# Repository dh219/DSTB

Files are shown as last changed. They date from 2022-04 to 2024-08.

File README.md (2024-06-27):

## David's ST Booster (DSTB)

# WARNING 27 July 2024 #

I strongly recommend no new builds of this project for now. I believe there's a reliabiltiy of executing from AltRAM which I've not been able to get to the bottom of.

Memory tests pass reliably, but I think the approach to this design in combination with clock switching and attempting to service DMA is inherently flawed.

Unless I find a firmware fix, in which case I'll log that here, I recommend persuing other designs or waiting for a revision 2.

David.

---

#### A low-cost DIY 16MHz 68000 accelerator with 8MB fast AltRAM and optional ROM cacheing

Fitting into a small footprint, just 3mm wider than the 68000 socket into which this plugs, the board (\~$4) contains one XC95144XL-100 CPLD (\~$5), one 32Mbit TSSOP-II-54 SDRAM chip (~$5), two level-shifting buffers (\~$6), one 5 or 3.3V 66MHz oscillator in a 7x5mm package (\~$4) and a 3.3V LDO voltage regulator (\~$2) as the core components.

This provides all the interface between the ST and a 16MHz capable 68000. The 68000 will run at the oscillator frequency divided by four, so 16.5MHz in normal configuration.

The AltRAM runs at at full speed for a 16MHz processor, offering throughput of around 7.7MB/s compared to ST-RAM's 3.7MB/s.

Firmware source (ISE), board design files (KiCAD) and any source for support programs will be published at each release.

#### Cost & requirements

I anticipate a single board can be hand assembled for approximately 30USD. You may need to acquire a 16MHz capable DIP-64 68000 to pair with it if your old 8MHz chip cannot handle the faster clock.

#### Manual

At the moment, there is no manual. This will be written in due course.

There is a build video available at https://youtu.be/VHx3kat0Q6M

### Resistor Networks

All resistor networks are recommended, however if you have already carried out preventative maintenance on your ST board such that the bus resistor packs have been changed to 2k2 or lower, you may omit the resistor packs on the address and data bus (RN1-10).

Please note, RN11 is not a supplementary bus pull-up pack and is required for correct operation of the firmware.

#### Software

See https://github.com/dh219/DSTB-tools for the 'AltRAM' or 'AltROM' programs (NB. 'AltROM' hasn't been properly tested with later firmware builds & this board is not compatible with 'ExxosRAM.PRG').

EmuTOS automatically recognises and activate AltRAM.

---

*Copyright 2022 D Henderson, released under GPL2.0*

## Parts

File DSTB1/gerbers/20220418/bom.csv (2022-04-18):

Comment | Designator | Footprint | LCSC Part #
100n Unpolarized capacitor | C1,C3,C5,C7,C9 | C_0805_2012Metric_Pad1.18x1.45mm_HandSolder
10u Unpolarized capacitor | C4,C8,C10 | C_0805_2012Metric_Pad1.18x1.45mm_HandSolder
LED Light emitting diode | D1 | LED_0805_2012Metric_Pad1.15x1.40mm_HandSolder
IS42S16320D-7TL | IC1 | TSOP-II-54_22.2x10.16mm_P0.8mm
SN74CB3T3245PW Texas Instruments SN74CB3T3245DW, Bus Switch, 8 x 1:1, 2.3 3.6 V, 20-Pin SOIC | IC2,IC3 | TSSOP-20_4.4x6.5mm_P0.65mm | C7145
Conn_01x06_Male Generic connector, single row, 01x06, script generated (kicad-library-utils/schlib/autogen/connector/) | J1 | PinHeader_1x06_P2.54mm_Horizontal
1k Resistor | R1 | R_0805_2012Metric_Pad1.20x1.40mm_HandSolder
2k2 Resistor | R2 | C_0805_2012Metric_Pad1.18x1.45mm_HandSolder
3k3 4 resistor network, parallel topology | RN1,RN2,RN3,RN4,RN5,RN6,RN7,RN8,RN9,RN10,RN11 | R_Array_Convex_4x0603
68000D 16/32-bit Microprocessor | U1 | DIP-64_W22.86mm
68000D 16/32-bit Microprocessor | U2 | DIP-64_W22.86mm_Socket
XC95144XL-TQ100 CPLD, 144 Macrocells, 3200 Usable Gates | U3 | TQFP-100_14x14mm_P0.5mm
LT1129-3.3_SOT223 700mA Micropower Low drop-out regulator, Fixed Output 3.3V, SOT-223 | U4 | SOT-223-3_TabPin2
IQXO-70 Crystal Clock Oscillator, SMD package 7.5x5.0mm² | X1 | Oscillator_SMD_IQD_IQXO70-4Pin_7.5x5.0mm

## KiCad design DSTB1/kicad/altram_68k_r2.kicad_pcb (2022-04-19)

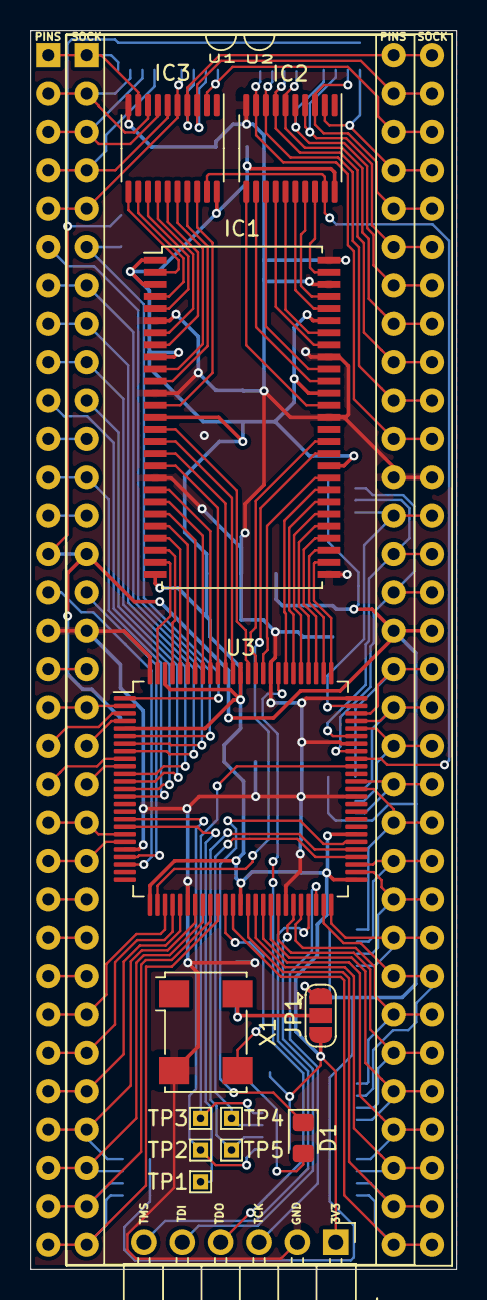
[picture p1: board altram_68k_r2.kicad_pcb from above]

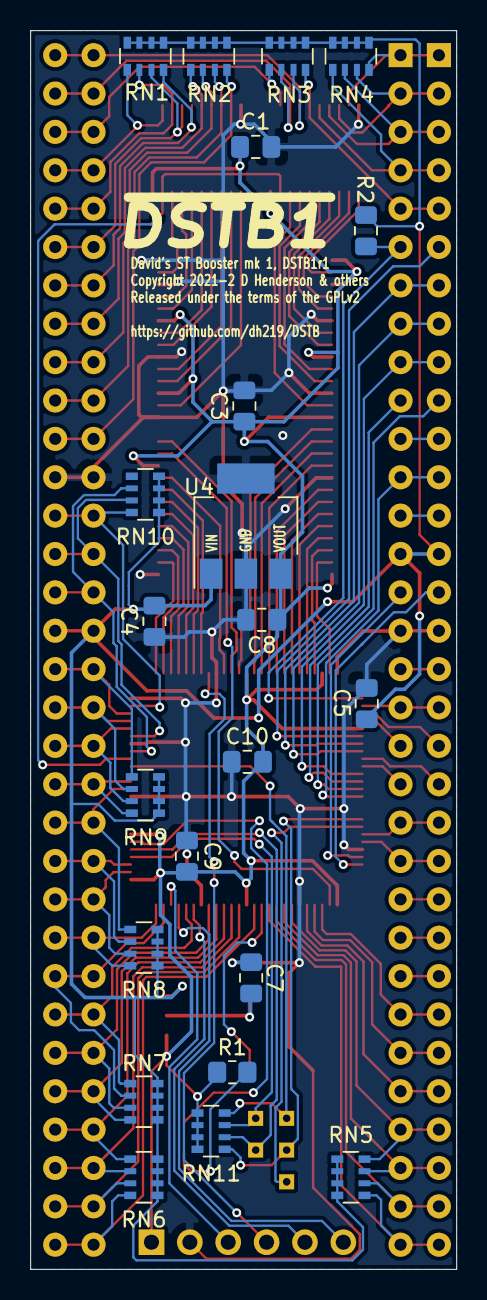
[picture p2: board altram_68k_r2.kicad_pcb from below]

Board: 2 copper layers, 28.2 x 82.0 mm, 37 parts (22 on the bottom side), 119 nets.

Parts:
C1, C3, C5, C7, C9: 100n; C_0805_2012Metric_Pad1.18x1.45mm_HandSolder
C4, C8, C10: 10u; C_0805_2012Metric_Pad1.18x1.45mm_HandSolder
D1: LED; LED_0805_2012Metric_Pad1.15x1.40mm_HandSolder
IC1: IS42S16320D-7TL; TSOP-II-54_22.2x10.16mm_P0.8mm
IC2, IC3: SN74CB3T3245PW; TSSOP-20_4.4x6.5mm_P0.65mm
J1: Conn_01x06_Male; PinHeader_1x06_P2.54mm_Horizontal
JP1: SolderJumper_3_Open; SolderJumper-3_P1.3mm_Open_RoundedPad1.0x1.5mm
R1: R; R_0805_2012Metric_Pad1.20x1.40mm_HandSolder
R2: 2k2; C_0805_2012Metric_Pad1.18x1.45mm_HandSolder
RN1, RN2, RN3, RN4, RN5, RN6, RN7, RN8, RN9, RN10, RN11: 3k3; R_Array_Convex_4x0603
TP1, TP2, TP3, TP4, TP5: TestPoint; TestPoint_THTPad_1.0x1.0mm_Drill0.5mm
U1: 68000D; DIP-64_W22.86mm
U2: 68000D; DIP-64_W22.86mm_Socket
U3: XC95144XL-TQ100; TQFP-100_14x14mm_P0.5mm
U4: LT1129-3.3_SOT223; SOT-223-3_TabPin2
X1: IQXO-70; Oscillator_SMD_IQD_IQXO70-4Pin_7.5x5.0mm

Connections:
/LED1: D1.1, U3.56
/TCK: J1.3, U3.48
/TDI: J1.5, U3.45
/TDO: J1.4, U3.83
/TMS: J1.6, U3.47
/TP1: TP1.1, U3.18
/TP2: RN11.1, TP2.1, U3.17
/TP3: RN11.4, TP3.1, U3.66
/TP4: RN11.3, TP4.1, U3.54
/TP5: RN11.2, TP5.1, U3.55
A1: RN5.8, U1.29, U2.29, U3.32
A2: RN5.7, U1.30, U2.30, U3.33
A3: RN5.6, U1.31, U2.31, U3.34
A4: RN5.5, U1.32, U2.32, U3.35
A5: RN6.8, U1.33, U2.33, U3.37
A6: RN6.7, U1.34, U2.34, U3.39
A7: RN6.6, U1.35, U2.35, U3.40
A8: RN6.5, U1.36, U2.36, U3.41
A9: RN7.8, U1.37, U2.37, U3.42
A10: RN7.7, U1.38, U2.38, U3.43
A11: RN7.5, U1.39, U2.39, U3.46
A12: RN7.6, U1.40, U2.40, U3.49
A13: RN8.8, U1.41, U2.41, U3.50
A14: RN8.7, U1.42, U2.42, U3.52
A15: RN8.6, U1.43, U2.43, U3.53
A16: RN8.5, U1.44, U2.44, U3.63
A17: RN9.8, U1.45, U2.45, U3.64
A18: RN9.7, U1.46, U2.46, U3.71
A19: RN9.6, U1.47, U2.47, U3.72
A20: RN9.5, U1.48, U2.48, U3.73
A21: RN10.6, U1.50, U2.50, U3.68
A22: RN10.7, U1.51, U2.51, U3.70
A23: RN10.8, U1.52, U2.52, U3.74
BA0: IC1.20, U3.92
BA1: IC1.21, U3.93
BG: U1.11, U2.11
BGK: U1.12, U2.12, U3.14
BR: U1.13, U2.13
CLK8: U1.15, U3.23
CLKOUT: U2.15, U3.22
D0: IC3.5, RN3.4, U1.5, U2.5
D1: IC3.6, RN4.1, U1.4, U2.4
D2: IC3.7, RN4.2, U1.3, U2.3
D3: IC3.8, RN4.3, U1.2, U2.2
D4: IC3.9, RN4.4, U1.1, U2.1
D5: IC3.4, RN3.3, U1.64, U2.64
D6: IC3.3, RN3.2, U1.63, U2.63
D7: IC3.2, RN3.1, U1.62, U2.62
D8: IC2.2, RN1.1, U1.61, U2.61
D9: IC2.3, RN1.2, U1.60, U2.60
D10: IC2.4, RN1.3, U1.59, U2.59
D11: IC2.5, RN1.4, U1.58, U2.58
D12: IC2.6, RN2.1, U1.57, U2.57
D13: IC2.7, RN2.2, U1.56, U2.56
D14: IC2.8, RN2.3, U1.55, U2.55
D15: IC2.9, RN2.4, U1.54, U2.54
DQM0: IC1.15, U3.87
DQM1: IC1.39, U3.86
E: U1.20, U3.9
E_INT: U2.20, U3.10
FC0: U1.28, U2.28, U3.30
FC1: U1.27, U2.27, U3.29
FC2: U1.26, U2.26, U3.28
GND: C1.2, C3.2, C4.1, C5.1, C7.2, C8.2, C9.1, C10.1, IC1.6, IC1.12, IC1.19, IC1.28, IC1.41, IC1.46, IC1.52, IC1.54, IC2.10, IC3.10, J1.2, U1.16, U1.53, U2.16, U2.53, U3.21, U3.31, U3.44, U3.62, U3.69, U3.75, U3.84, U3.100, U4.2, X1.2
IPL0: U1.25, U2.25
IPL1: U1.24, U2.24
IPL2: U1.23, U2.23
MA0: IC1.23, U3.95
MA1: IC1.24, U3.96
MA2: IC1.25, U3.97
MA3: IC1.26, U3.99
MA4: IC1.29, U3.76
MA5: IC1.30, U3.77
MA6: IC1.31, U3.78
MA7: IC1.32, U3.79
MA8: IC1.33, U3.80
MA9: IC1.34, U3.81
MA10: IC1.22, U3.94
MA11: IC1.35, U3.82
MA12: IC1.36, U3.85
MD0: IC1.53, IC2.18
MD1: IC1.51, IC2.17
MD2: IC1.50, IC2.16
MD3: IC1.48, IC2.15
MD4: IC1.47, IC2.14
MD5: IC1.45, IC2.13
MD6: IC1.44, IC2.12
MD7: IC1.42, IC2.11
MD8: IC1.13, IC3.18
MD9: IC1.11, IC3.17
MD10: IC1.10, IC3.16
MD11: IC1.8, IC3.15
MD12: IC1.7, IC3.14
MD13: IC1.5, IC3.13
MD14: IC1.4, IC3.12
MD15: IC1.2, IC3.11
unnamed: C7.1, JP1.2, X1.4
unnamed: D1.2, R1.2
OSC: U3.36, X1.3
RAMCLK: IC1.38, U3.27
R~W: U1.9, U2.9, U3.11
VCC: C4.2, C5.2, JP1.1, R2.1, RN1.5, RN1.6, RN1.7, RN1.8, RN2.5, RN2.6, RN2.7, RN2.8, RN3.5, RN3.6, RN3.7, RN3.8, RN4.5, RN4.6, RN4.7, RN4.8, RN5.1, RN5.2, RN5.3, RN5.4, RN6.1, RN6.2, RN6.3, RN6.4, RN7.1, RN7.2, RN7.3, RN7.4, RN8.1, RN8.2, RN8.3, RN8.4, RN9.1, RN9.2, RN9.3, RN9.4, RN10.1, RN10.2, RN10.3, RN10.4, U1.14, U1.49, U2.14, U2.49, U4.1
VCC3: C1.1, C3.1, C8.1, C9.2, C10.2, IC1.1, IC1.3, IC1.9, IC1.14, IC1.27, IC1.37, IC1.43, IC1.49, IC2.20, IC3.20, J1.1, JP1.3, R1.1, RN11.5, RN11.6, RN11.7, RN11.8, U3.5, U3.26, U3.38, U3.51, U3.57, U3.88, U3.98, U4.3
~AS: U1.6, U3.6
~AS_INT: R2.2, U2.6, U3.1
~BERR: U1.22, U2.22, U3.20
~BOE: IC2.19, IC3.19, U3.67
~CAS: IC1.17, U3.90
~DTACK: U1.10, U3.13
~DTACK_INT: U2.10, U3.12
~HLT: U1.17, U2.17
~LDS: U1.8, U2.8, U3.8
~RAMWE: IC1.16, U3.89
~RAS: IC1.18, U3.91
~RST: U1.18, U2.18, U3.2
~UDS: U1.7, U2.7, U3.7
~VMA: U1.19, U3.3
~VMA_INT: U2.19, U3.4
~VPA: U1.21, U2.21, U3.19

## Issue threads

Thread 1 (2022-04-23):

Quartz 66.000MHz

luciust, 2022-04-23:
This could be either 3.3V or 5V version? What is your source?

dh219, 2022-04-25:
Yes, the circuit board supports selecting 3V3 or 5V. Any 7x5mm oscillator up to 66MHz should work. I happened to have some in my parts bin, but I normally source from Farnell UK. They presently have 64MHz oscillators which would be fine. The CPU will run at OSC/4. The SDRAM controller cannot work beyond 66MHz. A 50MHz oscillator will work fine, but the CPU will run at 12.5MHz, therefore.

luciust, 2022-04-25:
Thanks, found the 66MHz in correct package, appreciate the additional comments!

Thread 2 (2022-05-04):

The Kicad project is missing the "david" and "SN74CB3T3245DW" libraries.

pi1541, 2022-05-04:
The schematic references;
david:68000D_PLUG
david:IS42S16320D-7TL
SN74CB3T3245DW:SN74CB3T3245DW

these are missing from the folder/project.
Therefore the schematic symbols are missing in the schematic view and appear as "??".

Perhaps export them to the local project.

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

dh219, 2022-05-04:
Sorry, you're right. I need to refactor these projects to remove external dependencies.

In the short term, as a work around, the libraries are avalable in the DFB repository: https://github.com/dh219/DFB/tree/main/DFB1/kicad5/kicad-libraries

dh219, 2022-05-31:
I believe this is now resolved. Thanks for the report.

Closed 2022-05-31.

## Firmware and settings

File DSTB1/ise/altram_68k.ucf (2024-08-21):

#r2 
#NET CKE  LOC = "P40"; # dropped in r2
#Created by Constraints Editor (xc95144xl-tq100-10) - 2022/05/10
NET "CLKOSC" TNM_NET = CLKOSC;
NET "CLK8" TNM_NET = CLK8;
#PACE: Start of Constraints generated by PACE
NET "CLKOUT" TNM_NET = CLKOUT;

#PACE: Start of PACE I/O Pin Assignments
NET "A<10>"  LOC = "P43"  ; 
NET "A<11>"  LOC = "P46"  ; 
NET "A<12>"  LOC = "P49"  ; 
NET "A<13>"  LOC = "P50"  ; 
NET "A<14>"  LOC = "P52"  ; 
NET "A<15>"  LOC = "P53"  ; 
NET "A<16>"  LOC = "P63"  ; 
NET "A<17>"  LOC = "P64"  ; 
NET "A<18>"  LOC = "P71"  ; 
NET "A<19>"  LOC = "P72"  ; 
NET "A<1>"  LOC = "P32"  ; 
NET "A<20>"  LOC = "P73"  ; 
NET "A<21>"  LOC = "P68"  ; 
NET "A<22>"  LOC = "P70"  ; 
NET "A<23>"  LOC = "P74"  ; 
NET "A<2>"  LOC = "P33"  ; 
NET "A<3>"  LOC = "P34"  ; 
NET "A<4>"  LOC = "P35"  ; 
NET "A<5>"  LOC = "P37"  ; 
NET "A<6>"  LOC = "P39"  ; 
NET "A<7>"  LOC = "P40"  ; 
NET "A<8>"  LOC = "P41"  ; 
NET "A<9>"  LOC = "P42"  ; 
NET "AS"  LOC = "P6"  ; 
NET "AS_INT"  LOC = "P1"  ; 
NET "BA<0>"  LOC = "P92"  ; 
NET "BA<1>"  LOC = "P93"  ; 
NET "BERR"  LOC = "P20"  ; 
NET "BGK"  LOC = "P14"  ; 
NET "BOE"  LOC = "P67"  ; 
NET "CAS"  LOC = "P90"  ; 
NET "CLK8"  LOC = "P23" |BUFG = CLK ; 
NET "CLKOSC_OLD"  LOC = "P36"  ; 
NET "CLKOUT"  LOC = "P22"  ; 
NET "DQM<0>"  LOC = "P87"  ; 
NET "DQM<1>"  LOC = "P86"  ; 
NET "DTACK"  LOC = "P13"  ; 
NET "DTACK_INT"  LOC = "P12"  ; 
NET "E"  LOC = "P9"  ; 
NET "E_INT"  LOC = "P10"  ; 
NET "FC<0>"  LOC = "P30"  ; 
NET "FC<1>"  LOC = "P29"  ; 
NET "FC<2>"  LOC = "P28"  ; 
NET "LDS"  LOC = "P8"  ; 
NET "LED"  LOC = "P56"  ; 
NET "MA<0>"  LOC = "P95"  ; 
NET "MA<10>"  LOC = "P94"  ; 
NET "MA<11>"  LOC = "P82"  ; 
NET "MA<12>"  LOC = "P85"  ; 
NET "MA<1>"  LOC = "P96"  ; 
NET "MA<2>"  LOC = "P97"  ; 
NET "MA<3>"  LOC = "P99"  ; 
NET "MA<4>"  LOC = "P76"  ; 
NET "MA<5>"  LOC = "P77"  ; 
NET "MA<6>"  LOC = "P78"  ; 
NET "MA<7>"  LOC = "P79"  ; 
NET "MA<8>"  LOC = "P80"  ; 
NET "MA<9>"  LOC = "P81"  ; 
NET "CLKOSC"  LOC = "P27" | BUFG = CLK ; 
NET "RAMWE"  LOC = "P89"  ; 
NET "RAS"  LOC = "P91"  ; 
NET "RST"  LOC = "P2"  ; 
NET "RW"  LOC = "P11"  ; 
NET "TP<1>"  LOC = "P18"  ; 
NET "TP<2>"  LOC = "P17"  ; 
NET "TP<3>"  LOC = "P66"  ; 
NET "TP<4>"  LOC = "P54"  ; 
NET "TP<5>"  LOC = "P55"  ; 
NET "UDS"  LOC = "P7"  ; 
NET "VMA"  LOC = "P3"  ; 
NET "VMA_INT"  LOC = "P4"  ; 
NET "VPA"  LOC = "P19"  ; 

#PACE: Start of PACE Area Constraints
#PACE: Start of PACE Prohibit Constraints
#PACE: End of Constraints generated by PACE
#Created by Constraints Editor (xc95144xl-tq100-10) - 2024/07/23
TIMESPEC TS_CLKOSC = PERIOD "CLKOSC" 66 MHz HIGH 50%;
#Created by Constraints Editor (xc95144xl-tq100-10) - 2024/07/23


#NET "CLK_D<1>" TNM_NET = CLK_D;
#TIMESPEC TS_CLK_D = PERIOD "CLK_D" 66 MHz HIGH 50%;
#NET "CLKOSC_2" TNM_NET = CLKOSC_2;
#TIMESPEC TS_CLKOSC_2 = PERIOD "CLKOSC_2" 33 MHz HIGH 50%;
#NET "CLKOSC_4" TNM_NET = CLKOSC_4;
#TIMESPEC TS_CLKOSC_4 = PERIOD "CLKOSC_4" 16.5 MHz HIGH 50%;

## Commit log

2022-04-18 Seeding the build files + verilog for DSTB1. Kicad to follow once libraries are sorted out.
    [altram_68k_r2-B_Cu.gbr, altram_68k_r2-B_Mask.gbr, altram_68k_r2-B_SilkS.gbr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]
2022-04-19 Adding Kicad 5 files for the release version
    [altram_68k_r2.kicad_pcb, altram_68k_r2.sch]
2022-05-10 Simplified state machine; speculative fix for RMW.
    [altram_68k.ucf]
2022-05-10 Changed the timer to work on the 66MHz osc
2022-05-24 Quick hack to support RMW at the expense of AltRAM speed to test stability on H5 boards.
2022-05-24 Inverting 8MHz/16MHz logic as reported working on H5 board
2022-05-31 Adding missing library dependencies
    [altram_68k_r2.sch]
2022-06-13 Resistor network requirement clarification.
2024-07-01 Working on a CKE-enabled SDRAM system using TP[1] and a hacked board.
2024-07-23 Trying out the SJ Leary Invert, Sample and Delay clock reconstruction technique. Also added extra time constraints. Needing a BR sensing line too.
    [altram_68k.ucf]
2024-08-04 Just tidying up some clock calculations to hopefully reduce jitter
2024-08-12 Current state of play has reads at 7.7MB/s but writes down at 5.
2024-08-12 Tiding up a bit. Given up with blitter for now. Need to react faster -- clever synchronisers don't cut it.
2026-10-20 Changed the LED to a combined speed/SDRAM indicator.
2026-11-10 TP1 passes out the sdram_access flag for the purposes of bus switching externally.

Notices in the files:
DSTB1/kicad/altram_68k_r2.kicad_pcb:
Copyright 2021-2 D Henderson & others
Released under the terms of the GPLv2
